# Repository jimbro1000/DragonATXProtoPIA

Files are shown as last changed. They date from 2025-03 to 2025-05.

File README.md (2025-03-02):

# Dragon 32 ATX Prototype PIA

This repository contains the KiCad project files
to produce the PIA component board for my
ATX Prototype backplane.

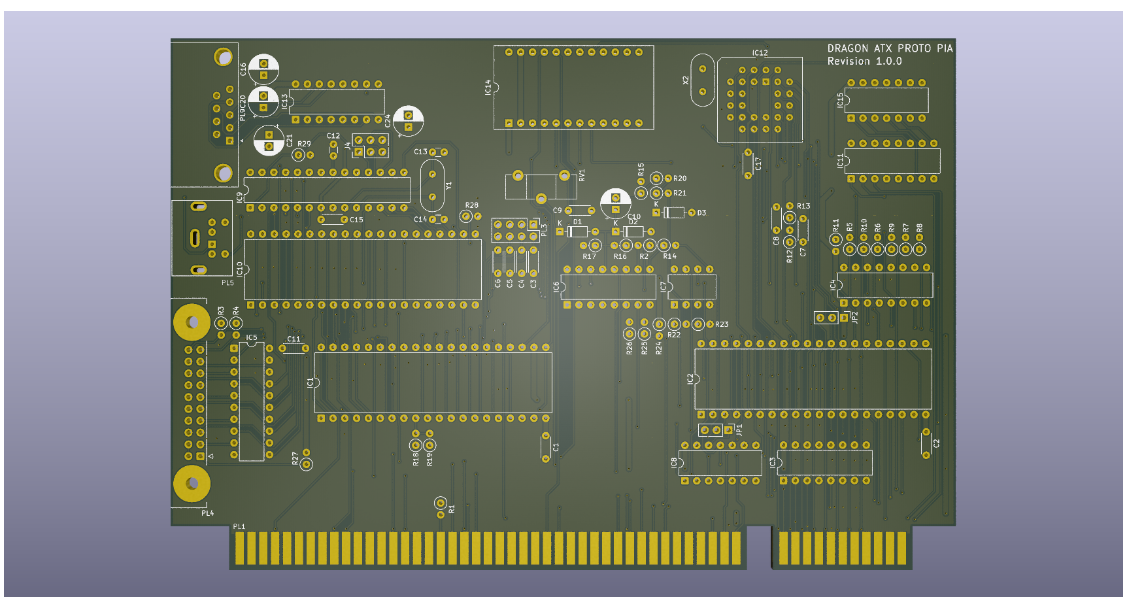
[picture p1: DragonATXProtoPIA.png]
Render of PCB top


This design requires the ATX backplane board in order 
to operate
See https://github.com/jimbro1000/DragonATXProto

## Notes

Revision 1 includes the standard 2 PIAs but also
provides footprints for a dedicated ACIA, as used
on the Dragon 64, and a RTC. Both these extras
utilise the redundant address mappings for PIA 0.

The ACIA and PIA can be omitted without any impact
to the functioning of the computer while in Dragon 32
mode. The ACIA must be present for Dragon 64 mode.

This design has been completed using KiCad 9. Earlier
versions of KiCad are not compatible.

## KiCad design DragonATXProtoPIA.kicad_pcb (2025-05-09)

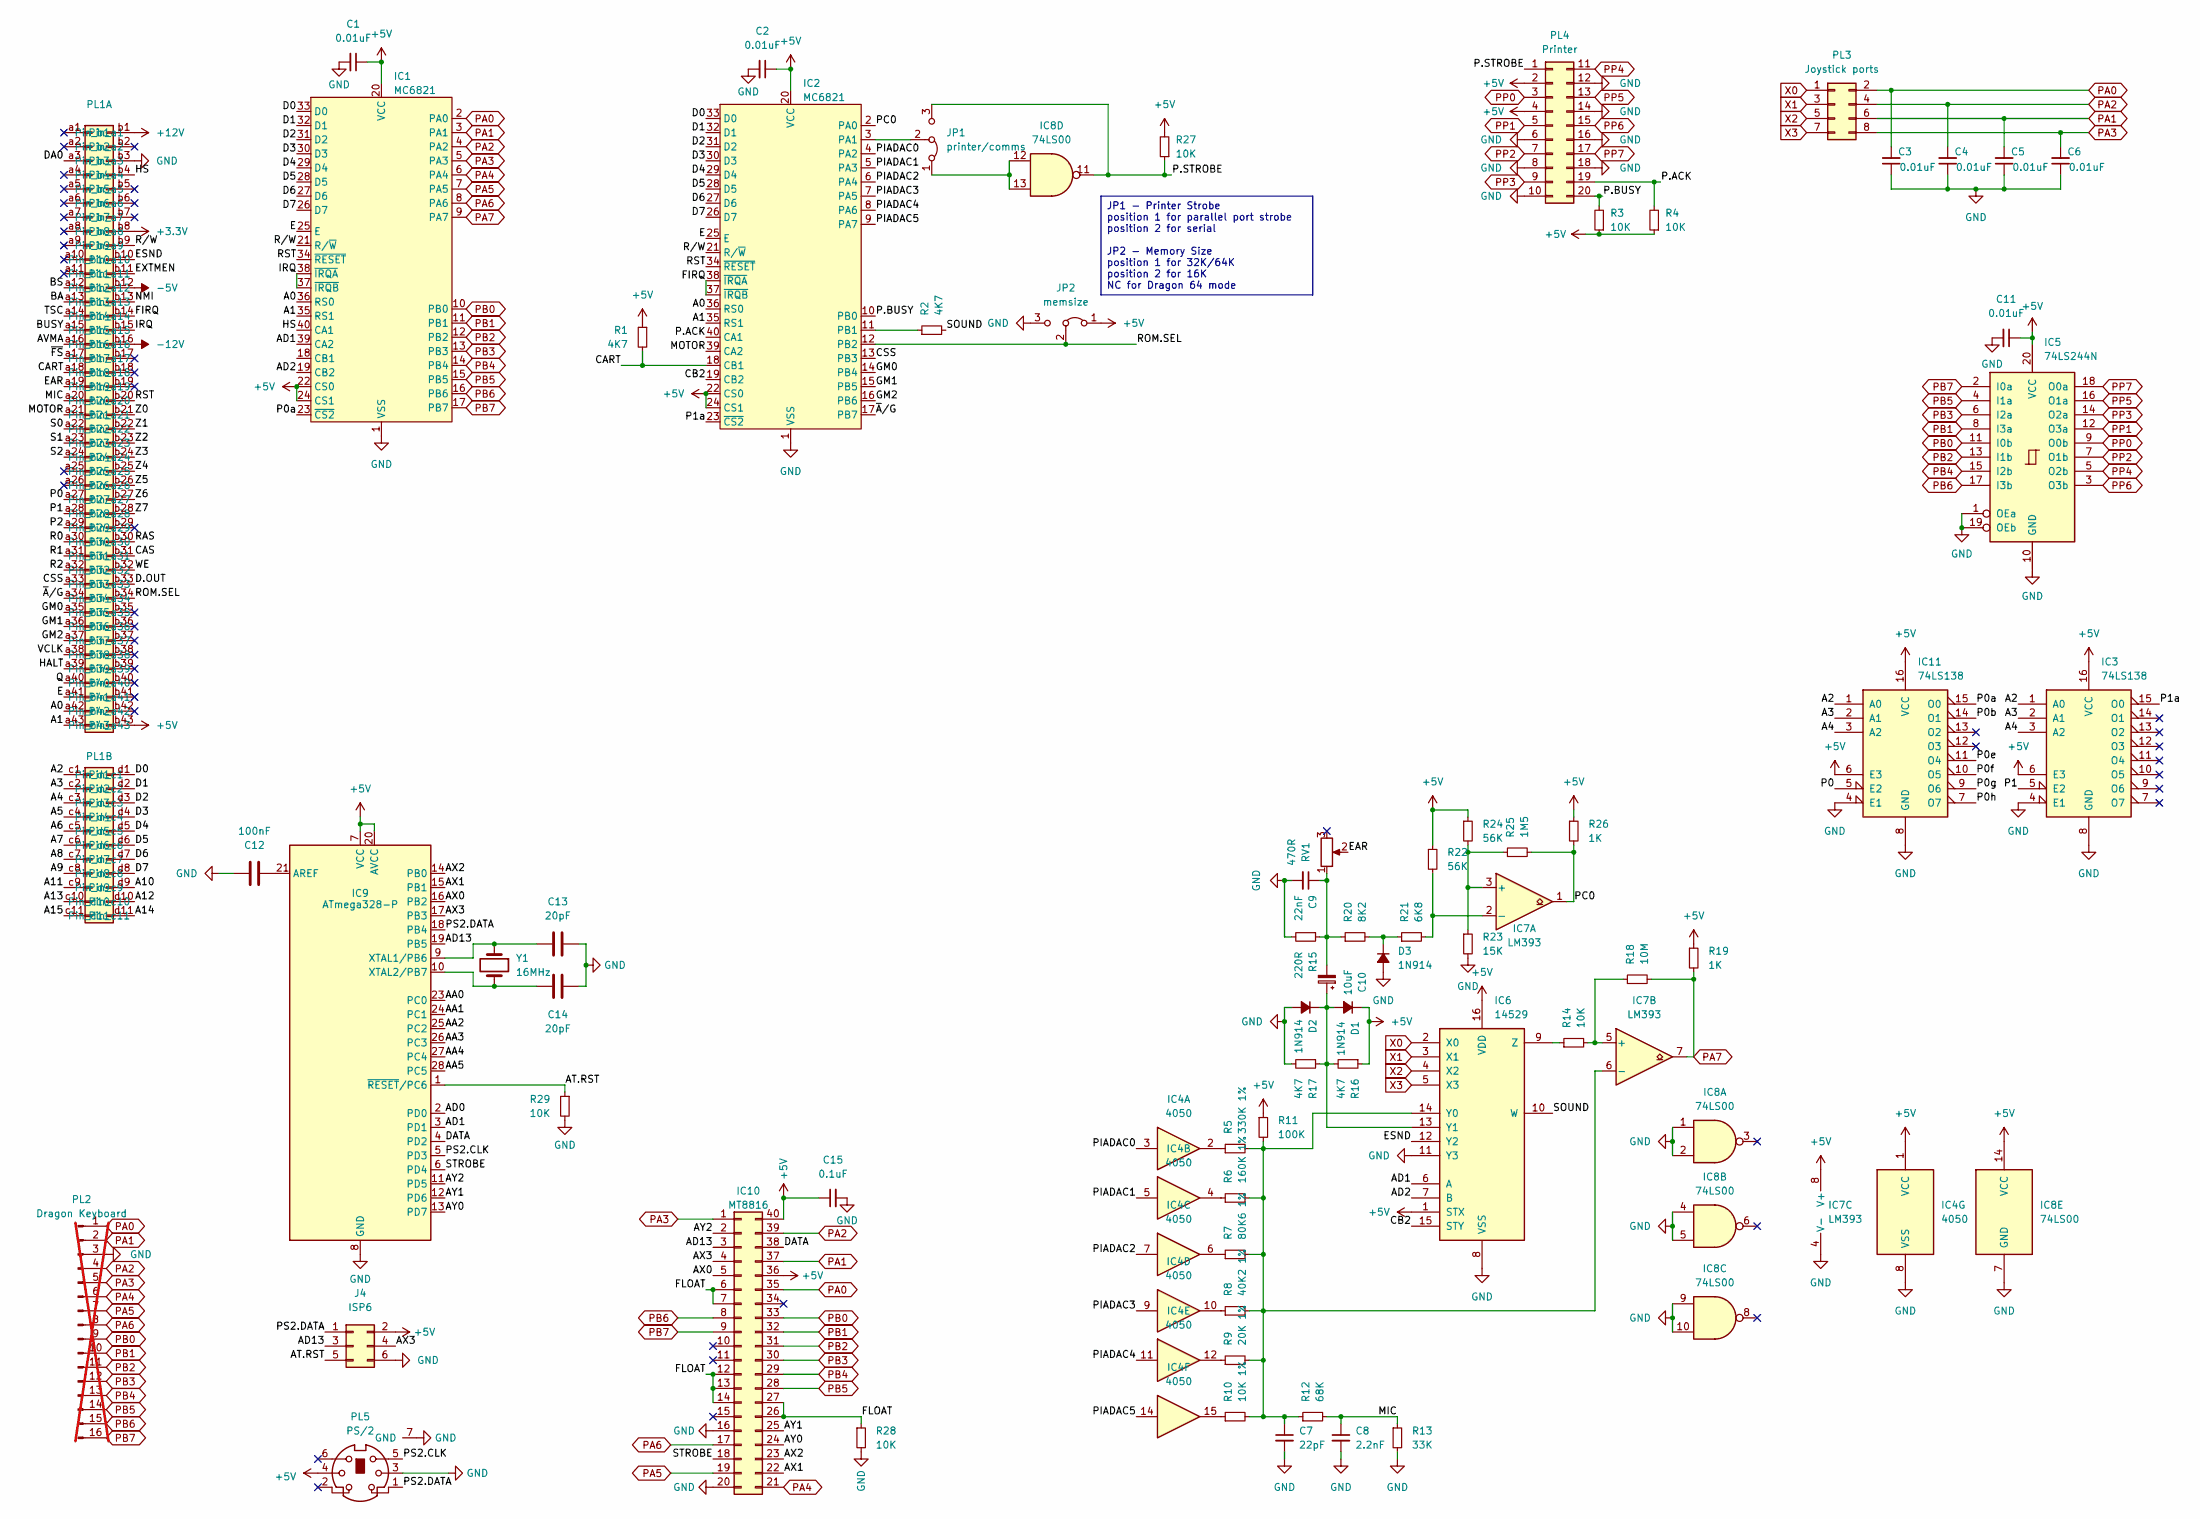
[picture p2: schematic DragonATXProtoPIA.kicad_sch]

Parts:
C1, C2, C11: 0.01uF; C_Disc_D4.3mm_W1.9mm_P5.00mm; DigiKey BC2662CT-ND
C3, C4, C5, C6: 0.01uF; C_Disc_D4.3mm_W1.9mm_P5.00mm; DigiKey BC1101CT-ND
C7: 22pF; C_Disc_D4.3mm_W1.9mm_P5.00mm; DigiKey BC2662CT-ND
C8: 2.2nF; C_Disc_D4.3mm_W1.9mm_P5.00mm; DigiKey BC2662CT-ND
C9: 22nF; C_Disc_D4.3mm_W1.9mm_P5.00mm; DigiKey BC2662CT-ND
C10: 10uF; CP_Radial_D6.3mm_P2.50mm
C12: 100nF; C_Disc_D3.0mm_W1.6mm_P2.50mm
C13, C14: 20pF; C_Disc_D3.0mm_W1.6mm_P2.50mm
C15: 0.1uF; C_Disc_D4.3mm_W1.9mm_P5.00mm; DigiKey BC2662CT-ND
D1, D2, D3: 1N914; D_DO-35_SOD27_P7.62mm_Horizontal; DigiKey 1N914FS-ND
IC1, IC2: MC6821; DIP-40_W15.24mm
IC3, IC11: 74LS138; DIP-16_W7.62mm
IC4: 4050; DIP-16_W7.62mm
IC5: 74LS244N; DIP-20_W7.62mm; DigiKey 296-1653-5-ND
IC6: 14529; DIP-16_W7.62mm
IC7: LM393; DIP-8_W7.62mm
IC8: 74LS00; DIP-14_W7.62mm
IC9: ATmega328-P; DIP-28_W7.62mm
IC10: MT8816; DIP-40_W15.24mm
J4: ISP6; PinHeader_2x03_P2.54mm_Vertical
JP1: printer/comms; PinHeader_1x03_P2.54mm_Vertical
JP2: memsize; PinHeader_1x03_P2.54mm_Vertical
PL1: Card_Edge
PL2: Dragon Keyboard; PinHeader_1x16_P2.54mm_Vertical; DigiKey 952-2521-ND; not fitted
PL3: Joystick ports; PinHeader_2x04_P2.54mm_Vertical
PL4: Printer; IDC-Header_2x10-1MP_P2.54mm_Latch_Horizontal; DigiKey CHR20G-ND
PL5: PS/2; Connector_DIN_Mini_Female_6
R1, R2, R16, R17: 4K7; R_Axial_DIN0207_L6.3mm_D2.5mm_P2.54mm_Vertical
R3, R4, R27: 10K; R_Axial_DIN0207_L6.3mm_D2.5mm_P2.54mm_Vertical; DigiKey CF14JT10K0CT-ND
R5: 330K 1%; R_Axial_DIN0207_L6.3mm_D2.5mm_P2.54mm_Vertical
R6: 160K 1%; R_Axial_DIN0207_L6.3mm_D2.5mm_P2.54mm_Vertical
R7: 80K6 1%; R_Axial_DIN0207_L6.3mm_D2.5mm_P2.54mm_Vertical
R8: 40K2 1%; R_Axial_DIN0207_L6.3mm_D2.5mm_P2.54mm_Vertical
R9: 20K 1%; R_Axial_DIN0207_L6.3mm_D2.5mm_P2.54mm_Vertical
R10: 10K 1%; R_Axial_DIN0207_L6.3mm_D2.5mm_P2.54mm_Vertical
R11: 100K; R_Axial_DIN0207_L6.3mm_D2.5mm_P2.54mm_Vertical
R12: 68K; R_Axial_DIN0207_L6.3mm_D2.5mm_P2.54mm_Vertical
R13: 33K; R_Axial_DIN0207_L6.3mm_D2.5mm_P2.54mm_Vertical
R14, R28, R29: 10K; R_Axial_DIN0207_L6.3mm_D2.5mm_P2.54mm_Vertical
R15: 220R; R_Axial_DIN0207_L6.3mm_D2.5mm_P2.54mm_Vertical
R18: 10M; R_Axial_DIN0207_L6.3mm_D2.5mm_P2.54mm_Vertical
R19, R26: 1K; R_Axial_DIN0207_L6.3mm_D2.5mm_P2.54mm_Vertical
R20: 8K2; R_Axial_DIN0207_L6.3mm_D2.5mm_P2.54mm_Vertical
R21: 6K8; R_Axial_DIN0207_L6.3mm_D2.5mm_P2.54mm_Vertical
R22, R24: 56K; R_Axial_DIN0207_L6.3mm_D2.5mm_P2.54mm_Vertical
R23: 15K; R_Axial_DIN0207_L6.3mm_D2.5mm_P2.54mm_Vertical
R25: 1M5; R_Axial_DIN0207_L6.3mm_D2.5mm_P2.54mm_Vertical
RV1: 470R; Potentiometer_Piher_PT-15-H05_Horizontal
Y1: 16MHz; Crystal_HC49-U_Vertical

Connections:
+3.3V: PL1.b8
+5V: C1.1, C2.1, C11.1, C15.1, D1.1 (K), IC1.20 (VCC), IC1.22 (CS0), IC1.24 (CS1), IC2.20 (VCC), IC2.22 (CS0), IC2.24 (CS1), IC3.6 (E3), IC3.16 (VCC), IC4.1 (VCC), IC5.20 (VCC), IC6.1 (STX), IC6.16 (VDD), IC7.8 (V+), IC8.14 (VCC), IC9.7 (VCC), IC9.20 (AVCC), IC10.36, IC10.40, IC11.6 (E3), IC11.16 (VCC), J4.2, JP2.1 (A), PL1.b43, PL4.2, PL4.4, PL5.4, R1.1, R3.1, R4.1, R11.1, R16.1, R19.1, R22.1, R24.1, R26.1, R27.2
+12V: PL1.b1
-5V: PL1.b12
-12V: PL1.b16
/A0: IC1.36 (RS0), IC2.36 (RS0), PL1.a42
/A1: IC1.35 (RS1), IC2.35 (RS1), PL1.a43
/A2: IC3.1 (A0), IC11.1 (A0), PL1.c1
/A3: IC3.2 (A1), IC11.2 (A1), PL1.c2
/A4: IC3.3 (A2), IC11.3 (A2), PL1.c3
/A5: PL1.c4
/A6: PL1.c5
/A7: PL1.c6
/A8: PL1.c7
/A9: PL1.c8
/A10: PL1.d9
/A11: PL1.c9
/A12: PL1.d10
/A13: PL1.c10
/A14: PL1.d11
/A15: PL1.c11
/AA0: IC9.23 (PC0)
/AA1: IC9.24 (PC1)
/AA2: IC9.25 (PC2)
/AA3: IC9.26 (PC3)
/AA4: IC9.27 (PC4)
/AA5: IC9.28 (PC5)
/AD0: IC9.2 (PD0)
/AD1: IC1.39 (CA2), IC6.6 (A), IC9.3 (PD1)
/AD2: IC1.19 (CB2), IC6.7 (B)
/AD13: IC9.19 (PB5), IC10.3, J4.3
/AT.RST: IC9.1 (~RESET/PC6), J4.5, R29.1
/AVMA: PL1.a16
/AX0: IC9.16 (PB2), IC10.5
/AX1: IC9.15 (PB1), IC10.22
/AX2: IC9.14 (PB0), IC10.23
/AX3: IC9.17 (PB3), IC10.4, J4.4
/AY0: IC9.13 (PD7), IC10.24
/AY1: IC9.12 (PD6), IC10.25
/AY2: IC9.11 (PD5), IC10.2
/BA: PL1.a13
/BS: PL1.a12
/BUSY: PL1.a15
/CART: IC2.18 (CB1), PL1.a18, R1.2
/CAS: PL1.b31
/CB2: IC2.19 (CB2), IC6.15 (STY)
/CSS: IC2.13 (PB3), PL1.a33
/D0: IC1.33 (D0), IC2.33 (D0), PL1.d1
/D1: IC1.32 (D1), IC2.32 (D1), PL1.d2
/D2: IC1.31 (D2), IC2.31 (D2), PL1.d3
/D3: IC1.30 (D3), IC2.30 (D3), PL1.d4
/D4: IC1.29 (D4), IC2.29 (D4), PL1.d5
/D5: IC1.28 (D5), IC2.28 (D5), PL1.d6
/D6: IC1.27 (D6), IC2.27 (D6), PL1.d7
/D7: IC1.26 (D7), IC2.26 (D7), PL1.d8
/D.OUT: PL1.b33
/DA0: PL1.a3
/DATA: IC9.4 (PD2), IC10.38
/E: IC1.25 (E), IC2.25 (E), PL1.a41
/EAR: PL1.a19, RV1.2
/ESND: IC6.12 (Y2), PL1.b10
/EXTMEN: PL1.b11
/FIRQ: IC2.37 (~IRQB), IC2.38 (~IRQA), PL1.b14
/FLOAT: IC10.6, IC10.7, IC10.12, IC10.13, IC10.14, IC10.26, IC10.27, R28.1
/GM0: IC2.14 (PB4), PL1.a35
/GM1: IC2.15 (PB5), PL1.a36
/GM2: IC2.16 (PB6), PL1.a37
/HALT: PL1.a39
/HS: IC1.40 (CA1), PL1.b4
/IRQ: IC1.37 (~IRQB), IC1.38 (~IRQA), PL1.b15
/MIC: C8.1, PL1.a20, R12.2, R13.1
/MOTOR: IC2.39 (CA2), PL1.a21
/NMI: PL1.b13
/P0: IC11.5 (E2), PL1.a27
/P0a: IC1.23 (~CS2), IC11.15 (O0)
/P0b: IC11.14 (O1)
/P0e: IC11.11 (O4)
/P0f: IC11.10 (O5)
/P0g: IC11.9 (O6)
/P0h: IC11.7 (O7)
/P1: IC3.5 (E2), PL1.a28
/P1a: IC2.23 (~CS2), IC3.15 (O0)
/P2: PL1.a29
/P.ACK: IC2.40 (CA1), PL4.19, R4.2
/P.BUSY: IC2.10 (PB0), PL4.20, R3.2
/P.STROBE: IC8.11, JP1.3 (B), PL4.1, R27.1
/PC0: IC2.2 (PA0), IC7.1, R25.2, R26.2
/PIADAC0: IC2.4 (PA2), IC4.3
/PIADAC1: IC2.5 (PA3), IC4.5
/PIADAC2: IC2.6 (PA4), IC4.7
/PIADAC3: IC2.7 (PA5), IC4.9
/PIADAC4: IC2.8 (PA6), IC4.11
/PIADAC5: IC2.9 (PA7), IC4.14
/PS2.CLK: IC9.5 (PD3), PL5.5
/PS2.DATA: IC9.18 (PB4), J4.1, PL5.1
/Q: PL1.a40
/R0: PL1.a30
/R1: PL1.a31
/R2: PL1.a32
/RAS: PL1.b30
/ROM.SEL: IC2.12 (PB2), JP2.2 (C), PL1.b34
/RST: IC1.34 (~RESET), IC2.34 (~RESET), PL1.b20
/R/W: IC1.21 (R/~W), IC2.21 (R/~W), PL1.b9
/S0: PL1.a22
/S1: PL1.a23
/S2: PL1.a24
/SOUND: IC6.10 (W), R2.2
/STROBE: IC9.6 (PD4), IC10.18
/TSC: PL1.a14
/VCLK: PL1.a38
/WE: PL1.b32
/Z0: PL1.b21
/Z1: PL1.b22
/Z2: PL1.b23
/Z3: PL1.b24
/Z4: PL1.b25
/Z5: PL1.b26
/Z6: PL1.b27
/Z7: PL1.b28
/~A/G: IC2.17 (PB7), PL1.a34
/~FS: PL1.a17
GND: C1.2, C2.2, C3.1, C4.1, C5.1, C6.1, C7.2, C8.2, C9.2, C11.2, C12.2, C13.2, C14.2, C15.2, D2.2 (A), D3.2 (A), IC1.1 (VSS), IC2.1 (VSS), IC3.4 (E1), IC3.8 (GND), IC4.8 (VSS), IC5.1 (OEa), IC5.10 (GND), IC5.19 (OEb), IC6.8 (VSS), IC6.11 (Y3), IC7.4 (V-), IC8.1, IC8.2, IC8.4, IC8.5, IC8.7 (GND), IC8.9, IC8.10, IC9.8 (GND), IC9.22 (GND), IC10.16, IC10.20, IC11.4 (E1), IC11.8 (GND), J4.6, JP2.3 (B), PL1.b3, PL2.3, PL4.6, PL4.8, PL4.10, PL4.12, PL4.14, PL4.16, PL4.18, PL5.3, PL5.7 (GND), R13.2, R15.2, R17.2, R23.2, R28.2, R29.2
unnamed: C9.1, C10.2, R15.1, R20.1, RV1.1
unnamed: C10.1, D1.2 (A), D2.1 (K), IC6.13 (Y1), R16.2, R17.1
unnamed: D3.1 (K), R20.2, R21.1
unnamed: IC2.3 (PA1), JP1.2 (C)
unnamed: IC2.11 (PB1), R2.1
unnamed: IC4.2, R5.1
unnamed: IC4.4, R6.1
unnamed: IC4.6, R7.1
unnamed: IC4.10, R8.1
unnamed: IC4.12, R9.1
unnamed: IC4.15, R10.1
unnamed: C7.1, IC6.14 (Y0), IC7.6 (-), R5.2, R6.2, R7.2, R8.2, R9.2, R10.2, R11.2, R12.1
unnamed: IC6.9 (Z), R14.1
unnamed: IC7.3 (+), R23.1, R24.2, R25.1
unnamed: IC7.2 (-), R21.2, R22.2
unnamed: IC7.5 (+), R14.2, R18.1
unnamed: C12.1, IC9.21 (AREF)
unnamed: C13.1, IC9.9 (XTAL1/PB6), Y1.1
unnamed: C14.1, IC9.10 (XTAL2/PB7), Y1.2
unnamed: IC8.12, IC8.13, JP1.1 (A)
PA0: C3.2, IC1.2 (PA0), IC10.35, PL2.1, PL3.2
PA1: C5.2, IC1.3 (PA1), IC10.37, PL2.2, PL3.6
PA2: C4.2, IC1.4 (PA2), IC10.39, PL2.4, PL3.4
PA3: C6.2, IC1.5 (PA3), IC10.1, PL2.5, PL3.8
PA4: IC1.6 (PA4), IC10.21, PL2.6
PA5: IC1.7 (PA5), IC10.19, PL2.7
PA6: IC1.8 (PA6), IC10.17, PL2.8
PA7: IC1.9 (PA7), IC7.7, R18.2, R19.2
PB0: IC1.10 (PB0), IC5.11 (I0b), IC10.33, PL2.9
PB1: IC1.11 (PB1), IC5.8 (I3a), IC10.32, PL2.10
PB2: IC1.12 (PB2), IC5.13 (I1b), IC10.31, PL2.11
PB3: IC1.13 (PB3), IC5.6 (I2a), IC10.30, PL2.12
PB4: IC1.14 (PB4), IC5.15 (I2b), IC10.29, PL2.13
PB5: IC1.15 (PB5), IC5.4 (I1a), IC10.28, PL2.14
PB6: IC1.16 (PB6), IC5.17 (I3b), IC10.8, PL2.15
PB7: IC1.17 (PB7), IC5.2 (I0a), IC10.9, PL2.16
PP0: IC5.9 (O0b), PL4.3
PP1: IC5.12 (O3a), PL4.5
PP2: IC5.7 (O1b), PL4.7
PP3: IC5.14 (O2a), PL4.9
PP4: IC5.5 (O2b), PL4.11
PP5: IC5.16 (O1a), PL4.13
PP6: IC5.3 (O3b), PL4.15
PP7: IC5.18 (O0a), PL4.17
X0: IC6.2 (X0), PL3.1
X1: IC6.3 (X1), PL3.3
X2: IC6.4 (X2), PL3.5
X3: IC6.5 (X3), PL3.7

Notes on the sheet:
JP1 - Printer Strobe position 1 for parallel port strobe position 2 for serial JP2 - Memory Size position 1 for 32K/64K position 2 for 16K NC for Dragon 64 mode

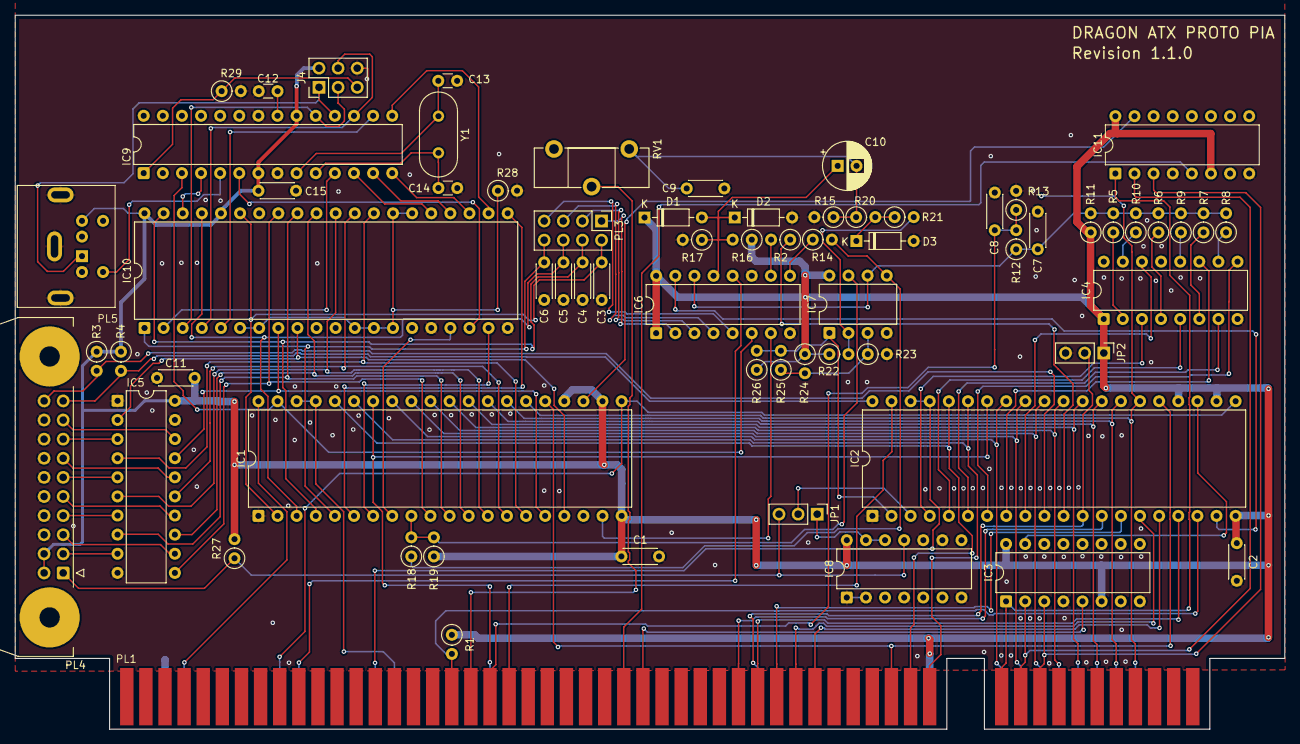
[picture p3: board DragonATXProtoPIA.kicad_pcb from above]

Board: 2 copper layers, 168.7 x 94.9 mm, 67 parts (0 on the bottom side), 112 nets.

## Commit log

2025-03-18 upgrade card edge spec
    [DragonATXProtoPIA.kicad_pcb]
2025-03-24 prepare for fabrication
    [DragonATXProtoPIA.kicad_pcb]
2025-05-07 Rectify slot edge and vertical dimensions
    [DragonATXProtoPIA.kicad_pcb, DragonATXProtoPIA.kicad_sch]
2025-05-07 shrink board
    [DragonATXProtoPIA.kicad_pcb, DragonATXProtoPIA.kicad_sch]
2025-05-08 shrink dimensions
    [DragonATXProtoPIA.kicad_pcb]
2025-05-08 remove uart and rtc
    [DragonATXProtoPIA.kicad_pcb, DragonATXProtoPIA.kicad_sch]
